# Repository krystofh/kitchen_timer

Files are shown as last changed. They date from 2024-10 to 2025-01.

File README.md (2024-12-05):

# Kitchen timer

Kitchen timer based on 4-digit 8-segment display 3461BS and RP Pico

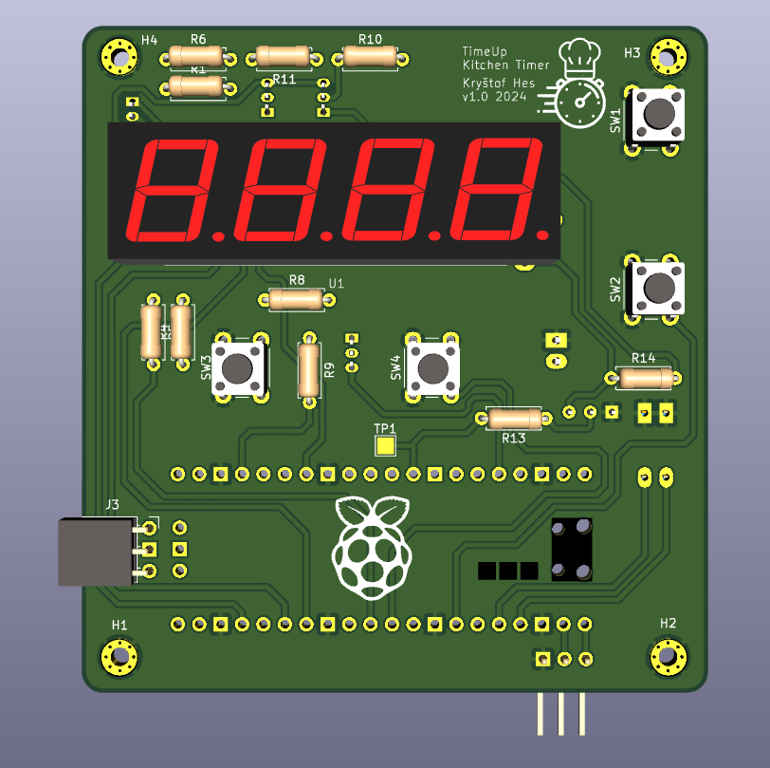
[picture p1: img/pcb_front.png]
||
|-|
|**Front view of the PCB**|

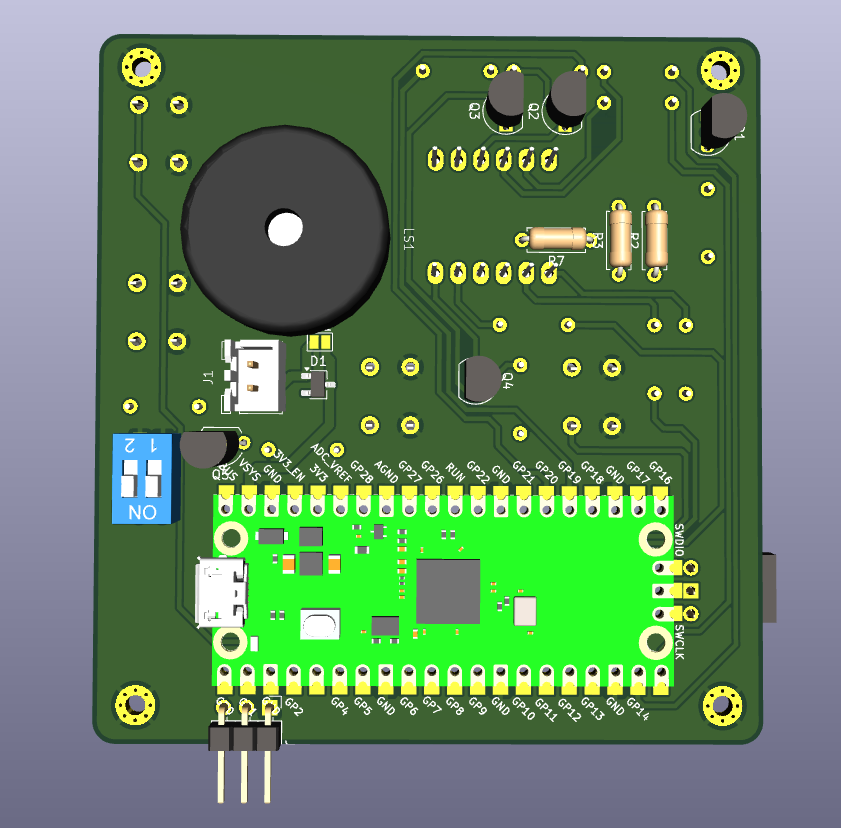
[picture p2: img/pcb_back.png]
||
|-|
|**Back view of the PCB**|

## Electronics

The used display is a common anode display. The datasheet specifies 10 mA typical current for the optical characteristics of a segment. The GPIOs of RP Pico can provide 12 mA max. The built-in `3V3OUT` voltage regulator can output up to 300 mA, which is sufficient for all 8 segemts. Not the full 32 segments are needed since the digits are displayed with a given refresh rate sequentially once at a time. Simulation using LTSpice and PNP transistor `BCS327-25` leads to the choice of resistor value

s with 220 Ohm and 22k. For the edge cases "1 segment" and "8 segments" the current limitations are fulfilled.

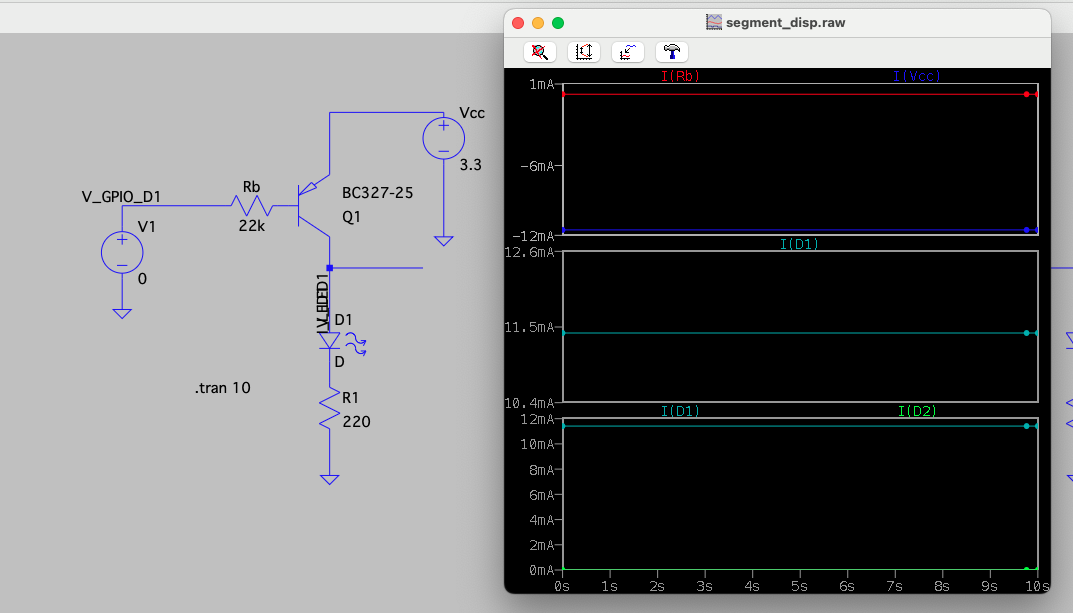
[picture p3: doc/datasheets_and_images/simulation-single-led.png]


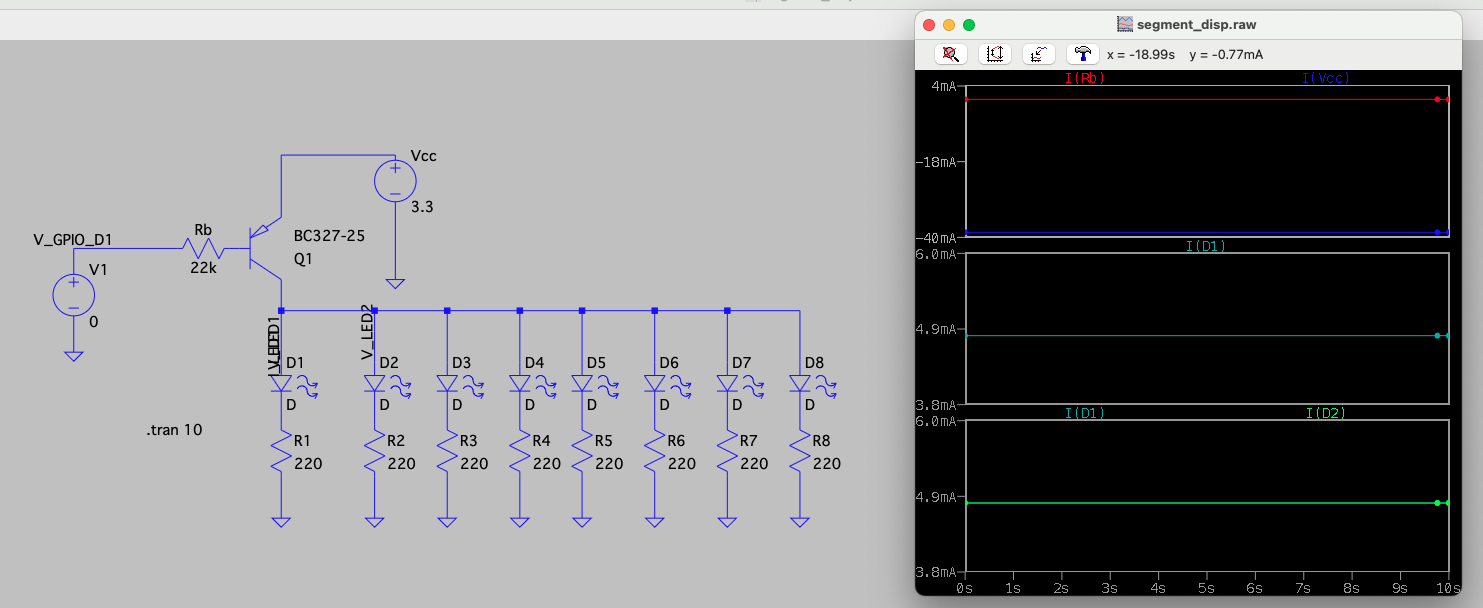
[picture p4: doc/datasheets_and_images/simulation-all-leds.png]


## Zephyr RTOS

### Setting PWM on a pin

1.  Start by enabling PWM in the `prj.conf` file: `CONFIG_PWM=y`
2.  In the `.overlay` file, enable the node `pwm_led0` by setting the status:
    ```c
    &pwm_led0 {
	status = "okay";
    };
    ```
3. Check the PWM generator corresponding to the GPIO. For RP Pico, these are:
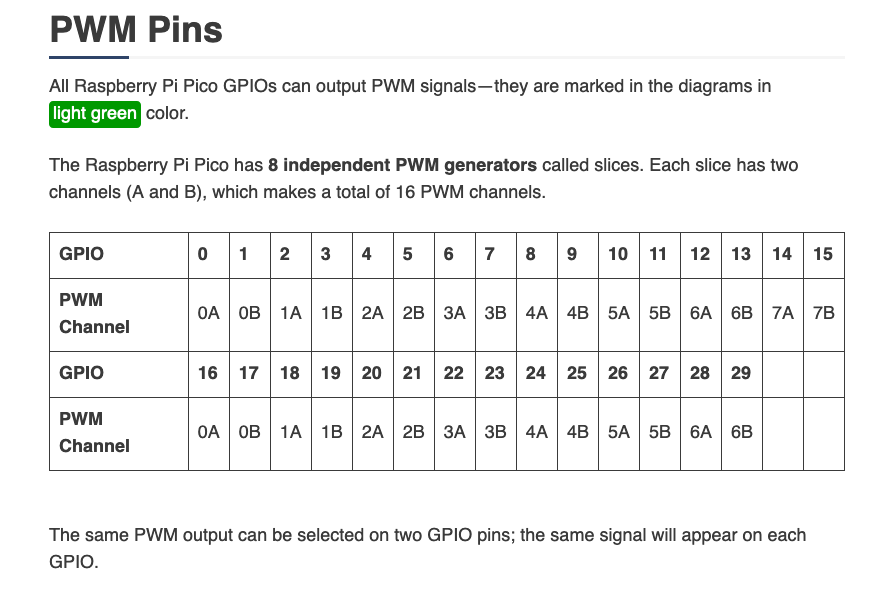
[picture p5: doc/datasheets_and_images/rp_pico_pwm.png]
PWM generators
    

    It results in a table:
    |PWM channel Nr.|PWM channel| GPIO|
    |-|-|-|
    |0|0A|0|
    |1|0B|1|
    |2|1A|2|
    |..|..|..|
    |15|7B|15|
    |0 ❗|0A|16|
    |1|0B|17|

    This means that to set PWM ON GPIO 27, we will need `PWM 5B` with the number `11`.

4. In the `.dts` file (not the overlay!), edit the `pwm_leds` node:
   ```c
    pwm_leds {
		compatible = "pwm-leds";
		status = "disabled";
		pwm_led0: pwm_led_0 {
			pwms = <&pwm 11 PWM_MSEC(20) PWM_POLARITY_NORMAL>;
			label = "PWM_LED";
		};
	};
   ```
5. Next, set the PWM on the specific pin. In the `rpi_pico-common.dtsi`:
   ```c
    &pwm {
	pinctrl-0 = <&pwm_ch5b_default>;
	pinctrl-names = "default";
    };
   ```
6. Finally, add the pinmux in `rpi_pico-pinctrl.dtsi` for GPIO 27:
   ```c
   pwm_ch5b_default: pwm_ch5b_default {
		group1 {
			pinmux = <PWM_5B_P27>;
		};
	};
   ```
7. Follow the examples such as [PWM Blinky](https://docs.zephyrproject.org/latest/samples/basic/blinky_pwm/README.html#pwm-blinky) and compile them with the changed devicetree. If it works, start coding your own application.

## Device tree definitions

Device tree nodes are aliased like in the picture below. The change from `-` to `_` is mandatory!

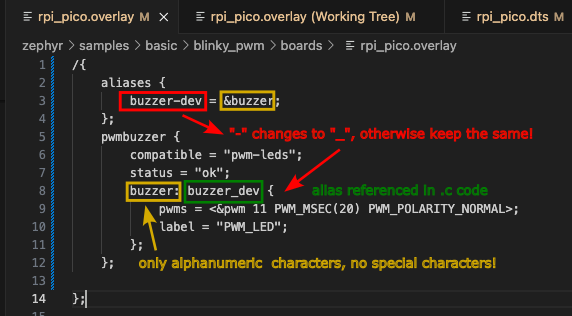
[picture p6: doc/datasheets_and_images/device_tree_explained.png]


In the `.c` code, the alias is used like:

```c
static const struct pwm_dt_spec my_variable = PWM_DT_SPEC_GET(DT_ALIAS(buzzer_dev));
```
 
## Links

- 
- https://www.electronics-tutorials.ws/blog/7-segment-display-tutorial.html
- https://www.instructables.com/12-Pin-7-Segment-Display-Wiring-Tutorial/
- https://www.reddit.com/r/AskElectronics/comments/oti47u/what_is_the_purpose_of_the_transistors_when_using/
- https://www.youtube.com/watch?v=sKJuzInKj_M
- https://www.youtube.com/watch?v=256VQ6eVNng
- https://www.youtube.com/watch?v=Fa7BHbPAM98

- Switch debouncing https://zephyrproject.org/how-to-debounce-button-inputs-in-a-rtos/
- PWM https://blog.golioth.io/adding-pwm-sound-in-zephyr/

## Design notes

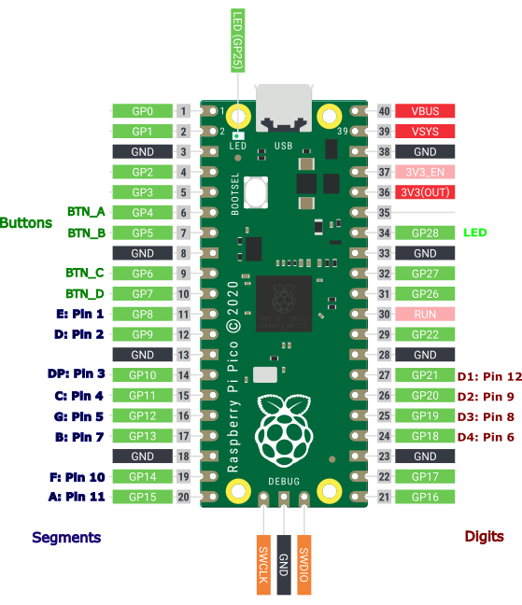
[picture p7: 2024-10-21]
electronics/datasheets_and_images/rp_pico_pinout..png

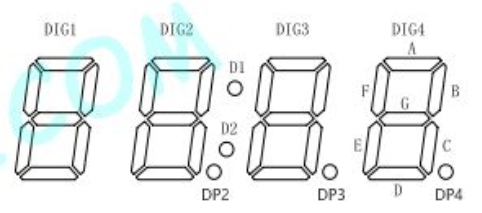
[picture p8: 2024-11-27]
electronics/kitchen_timer/display.png

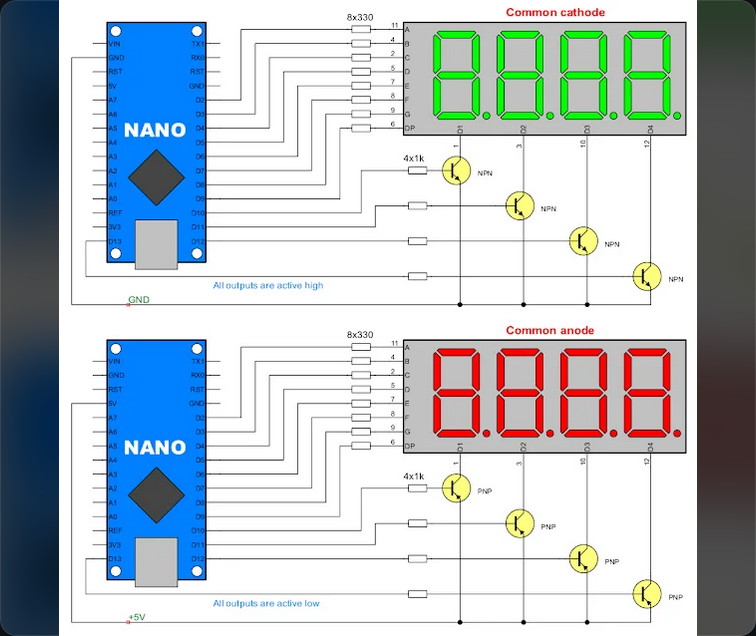
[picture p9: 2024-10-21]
electronics/datasheets_and_images/schematics-transistor.png

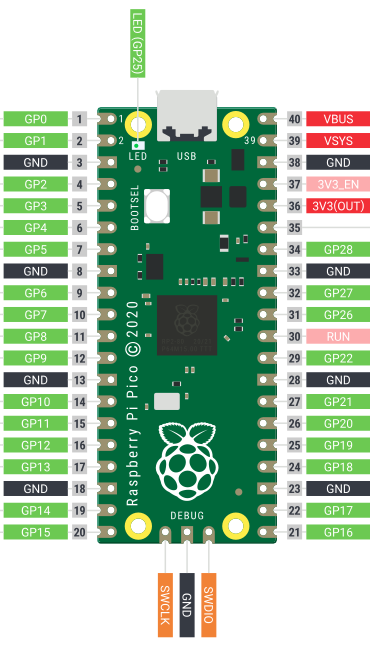
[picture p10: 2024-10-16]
electronics/datasheets_and_images/rp_pinout.png

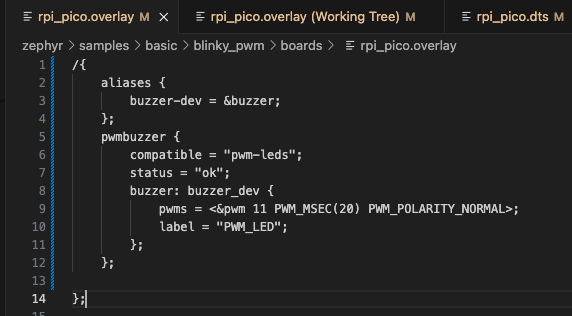
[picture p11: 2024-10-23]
img/device_tree.png

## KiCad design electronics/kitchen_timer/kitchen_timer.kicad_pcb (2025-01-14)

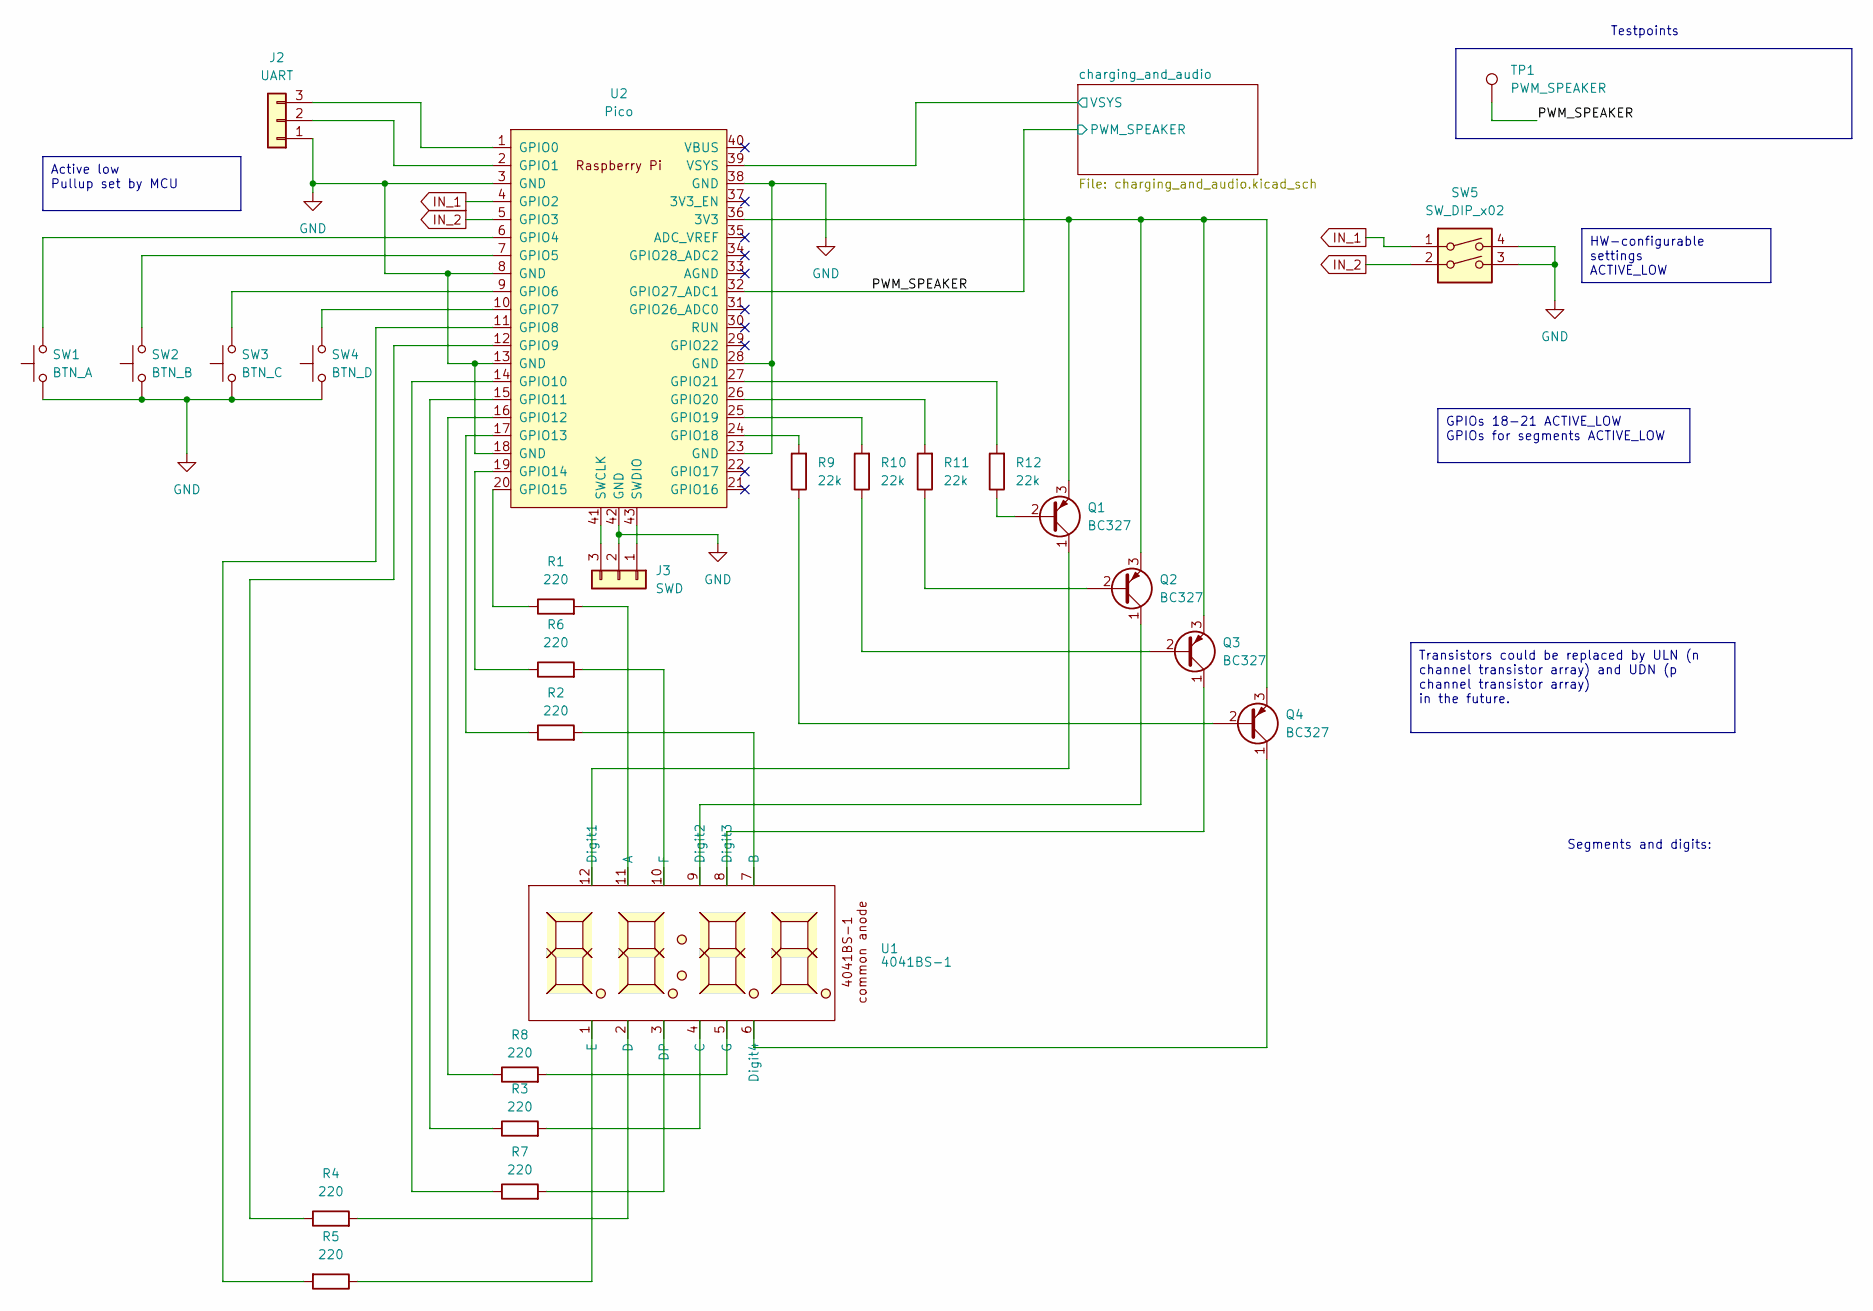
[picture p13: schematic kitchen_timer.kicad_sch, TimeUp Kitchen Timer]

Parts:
J2: UART; PinHeader_1x03_P2.54mm_Horizontal
J3: SWD; PinSocket_1x03_P2.54mm_Horizontal
Q1, Q2, Q3, Q4: BC327; TO-92_Inline
R1, R2, R3, R4, R5, R6, R7, R8: 220; R_Axial_DIN0207_L6.3mm_D2.5mm_P10.16mm_Horizontal
R9, R10, R11, R12: 22k; R_Axial_DIN0207_L6.3mm_D2.5mm_P10.16mm_Horizontal
SW1: BTN_A; SW_PUSH_6mm_H4.3mm
SW2: BTN_B; SW_PUSH_6mm_H4.3mm
SW3: BTN_C; SW_PUSH_6mm_H4.3mm
SW4: BTN_D; SW_PUSH_6mm_H4.3mm
SW5: SW_DIP_x02; DIP-4_W7.62mm_LongPads
TP1: PWM_SPEAKER; TestPoint_Pad_2.0x2.0mm
U1: 4041BS-1; Segment_display_4041BS-1
U2: Pico; RPi_Pico_SMD_TH

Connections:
/PWM_SPEAKER: TP1.1, U2.32 (GPIO27_ADC1); also elsewhere on the board
GND: J2.1, J3.2, SW1.1, SW2.1, SW3.1, SW4.1, SW5.3, SW5.4, U2.3 (GND), U2.8 (GND), U2.13 (GND), U2.18 (GND), U2.23 (GND), U2.28 (GND), U2.38 (GND), U2.42 (GND); also elsewhere on the board
IN_1: SW5.1, U2.4 (GPIO2)
IN_2: SW5.2, U2.5 (GPIO3)
unnamed: J2.2, U2.2 (GPIO1)
unnamed: J2.3, U2.1 (GPIO0)
unnamed: J3.1, U2.43 (SWDIO)
unnamed: J3.3, U2.41 (SWCLK)
unnamed: Q1.2 (B), R12.1
unnamed: Q1.1 (C), U1.12 (Digit1)
unnamed: Q1.3 (E), Q2.3 (E), Q3.3 (E), Q4.3 (E), U2.36 (3V3)
unnamed: Q2.2 (B), R11.1
unnamed: Q2.1 (C), U1.9 (Digit2)
unnamed: Q3.2 (B), R10.1
unnamed: Q3.1 (C), U1.8 (Digit3)
unnamed: Q4.2 (B), R9.1
unnamed: Q4.1 (C), U1.6 (Digit4)
unnamed: R1.2, U1.11 (A)
unnamed: R2.2, U1.7 (B)
unnamed: R3.2, U1.4 (C)
unnamed: R4.2, U1.2 (D)
unnamed: R7.2, U1.3 (DP)
unnamed: R5.1, U1.1 (E)
unnamed: R6.2, U1.10 (F)
unnamed: R8.2, U1.5 (G)
unnamed: SW1.2, U2.6 (GPIO4)
unnamed: SW2.2, U2.7 (GPIO5)
unnamed: SW3.2, U2.9 (GPIO6)
unnamed: SW4.2, U2.10 (GPIO7)
unnamed: R5.2, U2.11 (GPIO8)
unnamed: R4.1, U2.12 (GPIO9)
unnamed: R7.1, U2.14 (GPIO10)
unnamed: R3.1, U2.15 (GPIO11)
unnamed: R8.1, U2.16 (GPIO12)
unnamed: R2.1, U2.17 (GPIO13)
unnamed: R6.1, U2.19 (GPIO14)
unnamed: R1.1, U2.20 (GPIO15)
unnamed: R9.2, U2.24 (GPIO18)
unnamed: R10.2, U2.25 (GPIO19)
unnamed: R11.2, U2.26 (GPIO20)
unnamed: R12.2, U2.27 (GPIO21)

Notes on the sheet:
Active low Pullup set by MCU
Transistors could be replaced by ULN (n channel transistor array) and UDN (p channel transistor array) in the future.
HW-configurable settings ACTIVE_LOW
GPIOs 18-21 ACTIVE_LOW GPIOs for segments ACTIVE_LOW
Segments and digits:
Testpoints

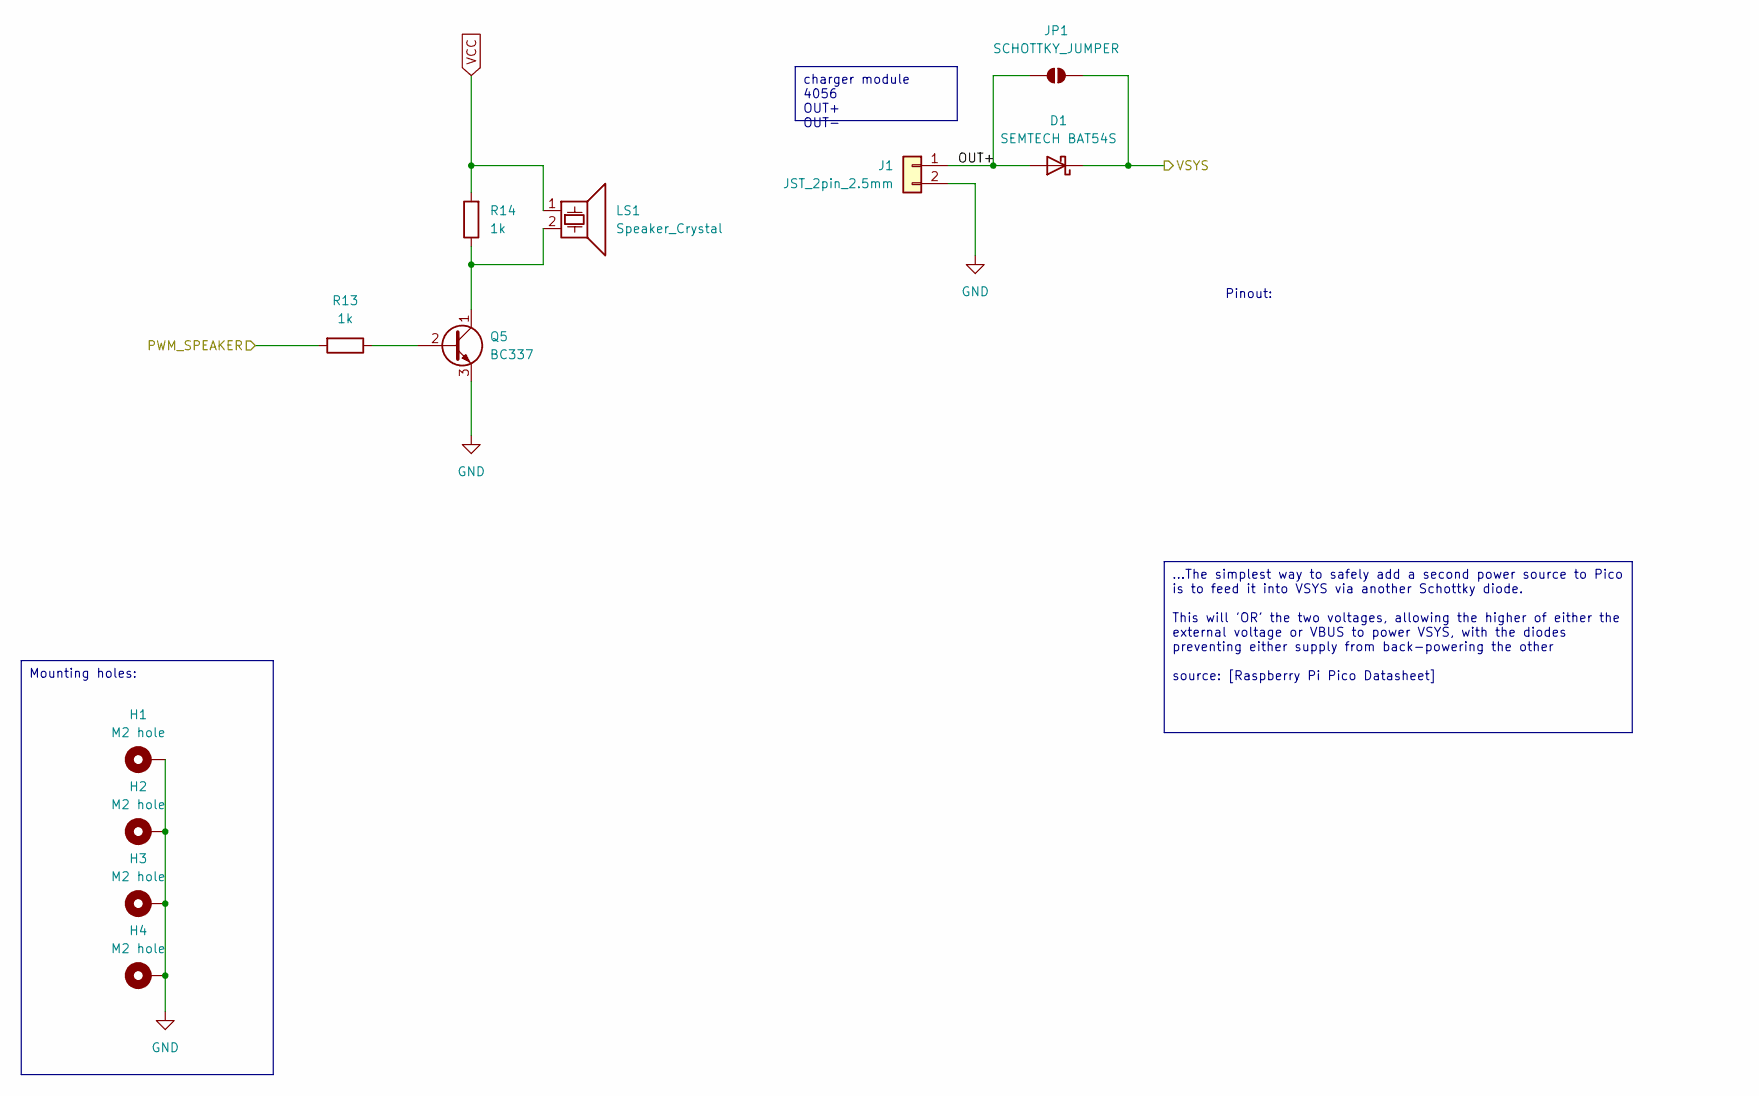
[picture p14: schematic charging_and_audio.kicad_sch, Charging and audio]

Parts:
D1: SEMTECH BAT54S; SOT-23_Handsoldering_renumbered
H1, H2, H3, H4: M2 hole; MountingHole_2.2mm_M2_Pad_Via
J1: JST_2pin_2.5mm; JST_2pin_2.54mm_female
JP1: SCHOTTKY_JUMPER; SolderJumper-2_P1.3mm_Open_TrianglePad1.0x1.5mm
LS1: Speaker_Crystal; Piezzo_10mm_6.5mm_combined
Q5: BC337; TO-92L_Inline_Wide
R13, R14: 1k; R_Axial_DIN0207_L6.3mm_D2.5mm_P10.16mm_Horizontal

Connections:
/PWM_SPEAKER: R13.2; also elsewhere on the board
GND: H1.1, H2.1, H3.1, H4.1, J1.2, Q5.3 (E); also elsewhere on the board
unnamed: Q5.2 (B), R13.1
unnamed: LS1.2, Q5.1 (C), R14.1
VCC: LS1.1, R14.2

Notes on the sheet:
...The simplest way to safely add a second power source to Pico is to feed it into VSYS via another Schottky diode. This will 'OR' the two voltages, allowing the higher of either the external voltage or VBUS to power VSYS, with the diodes preventing either supply from back-powering the other source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
Mounting holes:
charger module 4056 OUT+ OUT-
Pinout:

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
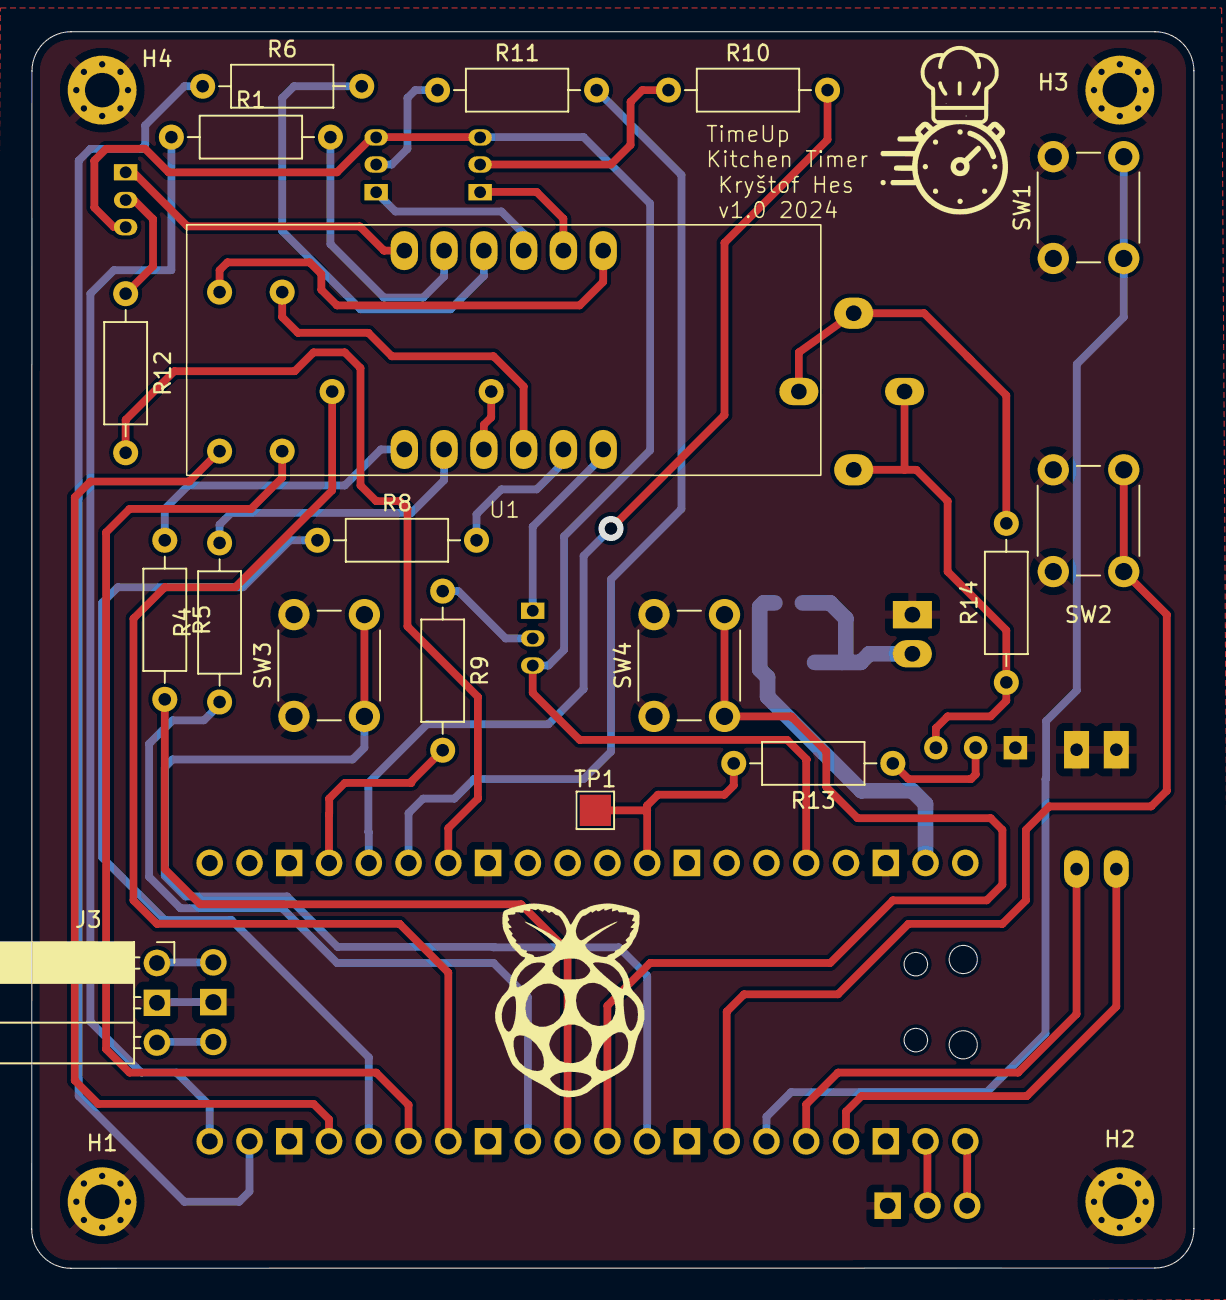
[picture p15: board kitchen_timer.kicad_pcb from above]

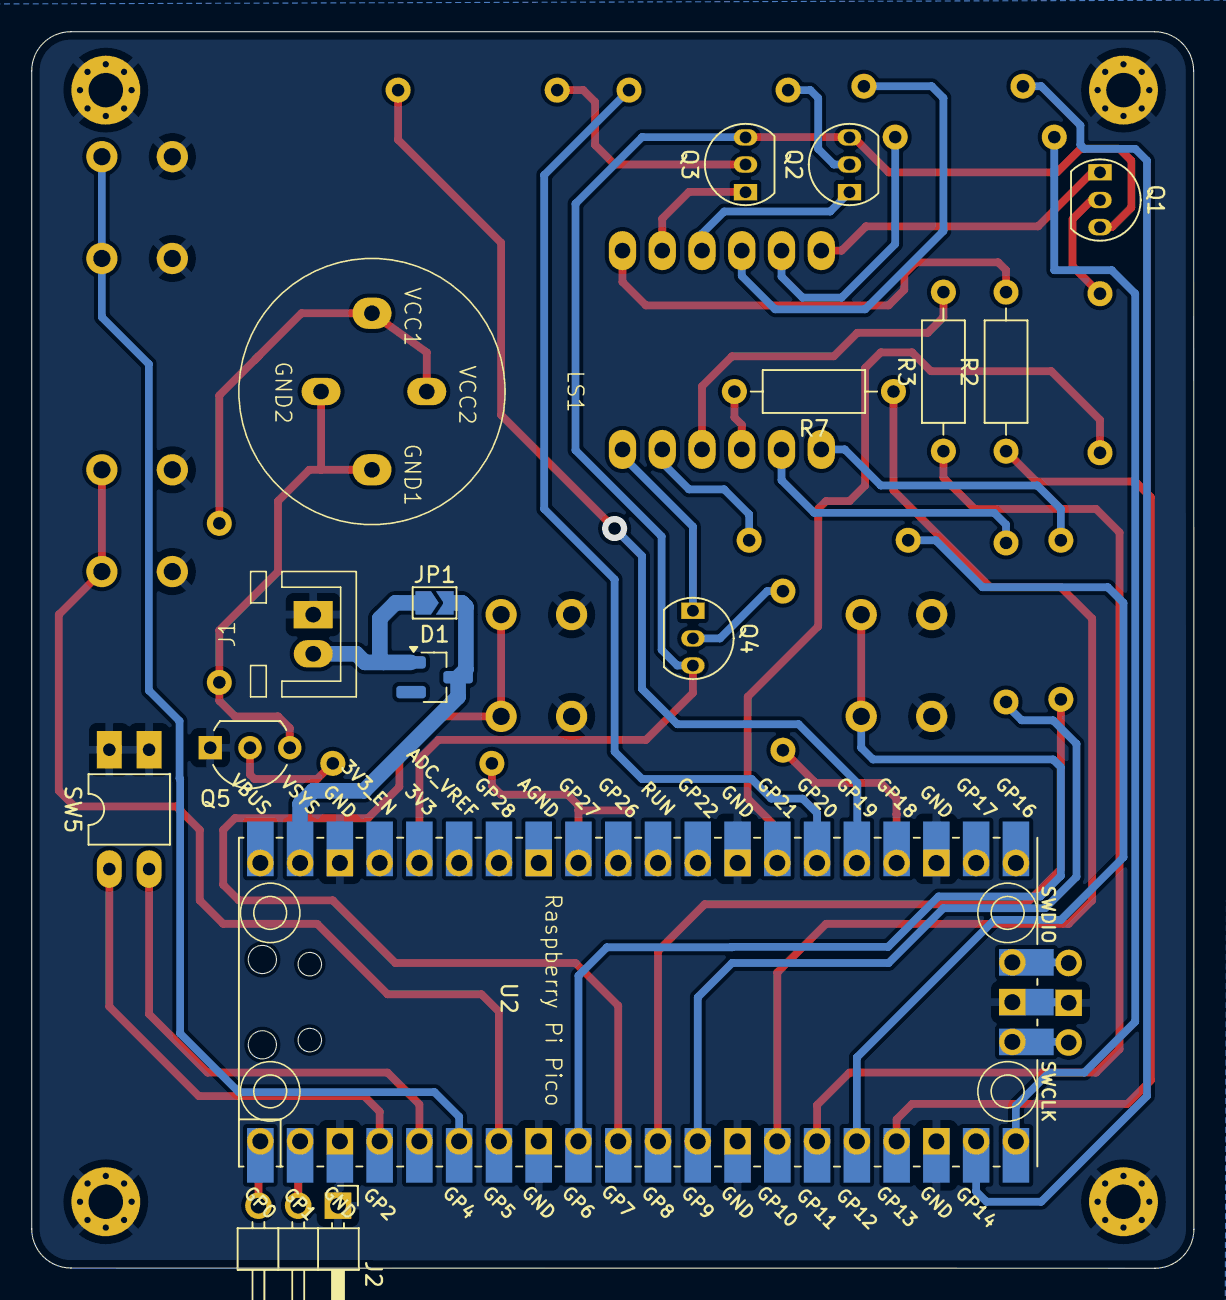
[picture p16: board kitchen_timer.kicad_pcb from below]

Board: 2 copper layers, 74.2 x 79.0 mm, 37 parts (15 on the bottom side), 46 nets.

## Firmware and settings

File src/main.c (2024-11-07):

/*
 * Copyright (c) 2016 Intel Corporation
 *
 * SPDX-License-Identifier: Apache-2.0
 */

#include <stdio.h>
#include <string.h>
#include <stdlib.h>
#include <ctype.h>

// Zephyr-specific libs
#include <zephyr/kernel.h>
#include <zephyr/drivers/gpio.h>
#include <zephyr/logging/log.h>
#include <zephyr/sys/printk.h>
#include <zephyr/sys/util.h>
#include <zephyr/usb/usb_device.h>
#include <zephyr/drivers/uart.h>
#include <zephyr/drivers/pwm.h>
// Shell libs
#include <zephyr/kernel.h>
#include <zephyr/shell/shell.h>
#include <zephyr/version.h>

// Own code
#include "display_driver.h"
#include "timer.h"
#include "event_handler.h"
#include "sound_player.h"

/* 1000 msec = 1 sec */
#define SLEEP_TIME_MS 20
// Define the alias for the onboard LED
#define STATUS_LED_NODE DT_NODELABEL(status_led)
/*
 * Ensure that an overlay for USB serial has been defined.
 */
BUILD_ASSERT(DT_NODE_HAS_COMPAT(DT_CHOSEN(zephyr_console), zephyr_cdc_acm_uart),
			 "Console device is not ACM CDC UART device");

LOG_MODULE_REGISTER(main, CONFIG_MAIN_LOG_LEVEL); // registers the log level for the module MAIN specified in Kconfig

const struct gpio_dt_spec status_led = GPIO_DT_SPEC_GET(STATUS_LED_NODE, gpios); // onboard LED device
const struct pwm_dt_spec buzzer = PWM_DT_SPEC_GET(DT_ALIAS(buzzer_dev));		 // buzzer for sound

// initialise all LED devices
int init_leds()
{
	int ret;
	if (!gpio_is_ready_dt(&status_led))
	{
		return 1;
	}
	ret = gpio_pin_configure_dt(&status_led, GPIO_OUTPUT_ACTIVE);
	if (ret < 0)
	{
		return 1;
	}
	return 0;
}

int main(void)
{
	LOG_INF("Program starting\n"); // example info message

	// Init sound
	init_sound(&buzzer);

	// Init the LED devices in logic 1 state
	if (init_leds())
	{
		LOG_ERR("LEDs could not be initialised!");
	}
	else
	{
		LOG_INF("LED devices initialised properly");
	}

	// Shell config
	const struct device *dev;
	uint32_t dtr = 0;
	dev = DEVICE_DT_GET(DT_CHOSEN(zephyr_shell_uart));
	if (!device_is_ready(dev) || usb_enable(NULL))
	{
		return 0;
	}
	uart_line_ctrl_get(dev, UART_LINE_CTRL_DTR, &dtr);
	k_sleep(K_MSEC(100));
	LOG_INF("USB device configured and connected");

	// Button config
	if (init_buttons())
	{
		LOG_ERR("Button init failed!");
	}
	else
	{
		LOG_INF("Button init successful!");
	}

	// Display init
	if (init_display())
	{
		LOG_ERR("Display init failed!");
	}
	else
	{
		LOG_INF("Display init successful!");
	}

	// Wait in this loop for shell commands or process messages
	while (true)
	{
		/* If we have an LED, match its state to the button's. */
		k_msleep(SLEEP_TIME_MS); /* sleep x ms*/
	}
	return 0;
}

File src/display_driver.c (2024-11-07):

#include "display_driver.h"

#define STACK_SIZE 1024
#define DISP_THREAD_PRIORITY 5

LOG_MODULE_REGISTER(display, CONFIG_DISPLAY_LOG_LEVEL);

// Digits GPIO configuration (active high)
const struct gpio_dt_spec digit_1 = GPIO_DT_SPEC_GET(DT_NODELABEL(d1), gpios);
const struct gpio_dt_spec digit_2 = GPIO_DT_SPEC_GET(DT_NODELABEL(d2), gpios);
const struct gpio_dt_spec digit_3 = GPIO_DT_SPEC_GET(DT_NODELABEL(d3), gpios);
const struct gpio_dt_spec digit_4 = GPIO_DT_SPEC_GET(DT_NODELABEL(d4), gpios);

// Segment GPIO configuration (active low)
const struct gpio_dt_spec seg_a = GPIO_DT_SPEC_GET(DT_NODELABEL(sega), gpios);
const struct gpio_dt_spec seg_b = GPIO_DT_SPEC_GET(DT_NODELABEL(segb), gpios);
const struct gpio_dt_spec seg_c = GPIO_DT_SPEC_GET(DT_NODELABEL(segc), gpios);
const struct gpio_dt_spec seg_d = GPIO_DT_SPEC_GET(DT_NODELABEL(segd), gpios);
const struct gpio_dt_spec seg_e = GPIO_DT_SPEC_GET(DT_NODELABEL(sege), gpios);
const struct gpio_dt_spec seg_f = GPIO_DT_SPEC_GET(DT_NODELABEL(segf), gpios);
const struct gpio_dt_spec seg_g = GPIO_DT_SPEC_GET(DT_NODELABEL(segg), gpios);
const struct gpio_dt_spec seg_dp = GPIO_DT_SPEC_GET(DT_NODELABEL(segdp), gpios);

// Digits and segments
const struct gpio_dt_spec *digits[] = {&digit_1, &digit_2, &digit_3, &digit_4};
const struct gpio_dt_spec *segments[] = {&seg_a, &seg_b, &seg_c, &seg_d, &seg_e, &seg_f, &seg_g, &seg_dp};
// Buffer to store the current digits to display
uint8_t display_buffer[4] = {0, 0, 0, 0};

// Digit encoding
// 7-segment encoding for digits 0-9
const uint8_t digit_codes[10] = {
    0b00111111, // 0
    0b00000110, // 1
    0b01011011, // 2
    0b01001111, // 3
    0b01100110, // 4
    0b01101101, // 5
    0b01111101, // 6
    0b00000111, // 7
    0b01111111, // 8
    0b01101111  // 9
};

// Spawn thread
K_THREAD_DEFINE(display_refresh_tid, STACK_SIZE, display_refresh_thread, NULL, NULL, NULL,
                DISP_THREAD_PRIORITY, 0, 0);

// Initialize the display GPIOs
int init_display()
{
    int ret;

    // Configure digit GPIOs
    ret = gpio_pin_configure_dt(&digit_1, GPIO_OUTPUT_INACTIVE);
    if (ret != 0)
        return ret;

    ret = gpio_pin_configure_dt(&digit_2, GPIO_OUTPUT_INACTIVE);
    if (ret != 0)
        return ret;

    ret = gpio_pin_configure_dt(&digit_3, GPIO_OUTPUT_INACTIVE);
    if (ret != 0)
        return ret;

    ret = gpio_pin_configure_dt(&digit_4, GPIO_OUTPUT_INACTIVE);
    if (ret != 0)
        return ret;

    // Configure segment GPIOs
    ret = gpio_pin_configure_dt(&seg_a, GPIO_OUTPUT_INACTIVE);
    if (ret != 0)
        return ret;

    ret = gpio_pin_configure_dt(&seg_b, GPIO_OUTPUT_INACTIVE);
    if (ret != 0)
        return ret;

    ret = gpio_pin_configure_dt(&seg_c, GPIO_OUTPUT_INACTIVE);
    if (ret != 0)
        return ret;

    ret = gpio_pin_configure_dt(&seg_d, GPIO_OUTPUT_INACTIVE);
    if (ret != 0)
        return ret;

    ret = gpio_pin_configure_dt(&seg_e, GPIO_OUTPUT_INACTIVE);
    if (ret != 0)
        return ret;

    ret = gpio_pin_configure_dt(&seg_f, GPIO_OUTPUT_INACTIVE);
    if (ret != 0)
        return ret;

    ret = gpio_pin_configure_dt(&seg_g, GPIO_OUTPUT_INACTIVE);
    if (ret != 0)
        return ret;

    ret = gpio_pin_configure_dt(&seg_dp, GPIO_OUTPUT_INACTIVE);
    if (ret != 0)
        return ret;

    LOG_INF("Display initialized");
    return 0;
}

void display_refresh_thread()
{
    while (1)
    {
        for (uint8_t i = 0; i < ARRAY_SIZE(digits); i++)
        {
            display_digit(display_buffer[i], i);
            k_sleep(K_MSEC(1000 / (ARRAY_SIZE(digits) * CONFIG_DISPLAY_FPS))); // period [ms]
        }
    }
}

// Simple demo showing sequentially all segments on all digits
int display_demo()
{
    bool enable_shutdown = false;
    // Iterate through each digit in digits
    for (int i = 0; i < ARRAY_SIZE(digits); i++)
    {
        // Turn off all segemnts first
        for (int m = 0; m < ARRAY_SIZE(segments); m++)
        {
            gpio_pin_set_dt(segments[m], 0);
        }

        // Turn off all digits first to prevent ghosting
        for (int j = 0; j < ARRAY_SIZE(digits); j++)
        {
            gpio_pin_set_dt(digits[j], 0);
        }

        // Activate current digit
        int response = gpio_pin_set_dt(digits[i], 1);

        // Light up each segment (A to G, DP) sequentially
        response = gpio_pin_set_dt(&seg_a, 1); // try out segment A
        k_sleep(K_MSEC(1000));
        if (enable_shutdown)
        {
            gpio_pin_set_dt(&seg_a, 0);
        };
        response = gpio_pin_set_dt(&seg_b, 1); // try out segment
        k_sleep(K_MSEC(1000));
        if (enable_shutdown)
        {
            response = gpio_pin_set_dt(&seg_b, 0); // try out segment
        };
        response = gpio_pin_set_dt(&seg_c, 1); // try out segment
        k_sleep(K_MSEC(1000));
        if (enable_shutdown)
        {
            response = gpio_pin_set_dt(&seg_c, 0); // try out segment
        };
        response = gpio_pin_set_dt(&seg_d, 1); // try out segment
        k_sleep(K_MSEC(1000));
        if (enable_shutdown)
        {
            response = gpio_pin_set_dt(&seg_d, 0); // try out segment
        };
        response = gpio_pin_set_dt(&seg_e, 1); // try out segment
        k_sleep(K_MSEC(1000));
        if (enable_shutdown)
        {
            response = gpio_pin_set_dt(&seg_e, 0); // try out segment
        }
        response = gpio_pin_set_dt(&seg_f, 1); // try out segment
        k_sleep(K_MSEC(1000));
        if (enable_shutdown)
        {
            response = gpio_pin_set_dt(&seg_f, 0); // try out segment
        }
        response = gpio_pin_set_dt(&seg_g, 1); // try out segment
        k_sleep(K_MSEC(1000));
        if (enable_shutdown)
        {
            response = gpio_pin_set_dt(&seg_g, 0); // try out segment
        }
        response = gpio_pin_set_dt(&seg_dp, 1); // try out segment
        k_sleep(K_MSEC(1000));
        if (enable_shutdown)
        {
            response = gpio_pin_set_dt(&seg_dp, 0); // try out segment
        };
    }
    return 0;
}

// Display a diven digit
// index - 0 to 3,  HH:MM
void display_digit(uint8_t digit, uint8_t index)
{
    reset_display(); // make sure only one digit is displayed at a time
    // prepare the digit's index (select the 8-bit segment)
    gpio_pin_set_dt(digits[index], 1);
    // draw the digit
    uint8_t temp_bin = digit_codes[digit];             // binary representation of digit
    for (uint8_t i = 0; i < ARRAY_SIZE(segments); i++) // go through one segment (bit) after the other
    {
        gpio_pin_set_dt(segments[i], temp_bin % 2); // if the bit is 1 -> set the segment ACTIVE
        temp_bin = temp_bin >> 1;                   // right shift after the bit is processed
    }
}
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

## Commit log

2024-10-16 empty west repo for rp pico
2024-10-16 prepared device tree
2024-10-16 minimal working example of button A
2024-10-21 added buttons C and D for future minute and second selection
2024-10-23 button debounce partly working
2024-10-23 device tree and electronics explanations
2024-11-07 corrected time pointers, added reset cmd
    [event_handler.c, main.c]
2024-11-07 timer min example
2024-11-07 refactor timer as separate file from event handler
2024-11-07 added start stop reset sounds
    [sound_player.c]
2024-11-08 alarm loop until button pressed
2024-11-16 change VID and PID and product
2024-11-20 Add debounce for all buttons
2024-11-20 Change button C function
    C can start and stop timer
    C can reset timer on longpress
    [event_handler.c]
2024-11-27 add electronics files
    [charging_and_audio.kicad_sch, kitchen_timer.kicad_pcb, kitchen_timer.kicad_sch]
2024-11-27 Add 3d models to components, small rerouting
    [charging_and_audio.kicad_sch, kitchen_timer.kicad_pcb, kitchen_timer.kicad_sch]
2024-12-05 Update electronics
    - added Schottky diode and solder bridge
    - corrected all errors from design rules checker
    - added silk screen logos
    [charging_and_audio.kicad_sch, kitchen_timer.kicad_pcb, kitchen_timer.kicad_sch]
2024-12-07 Update electronics
    - resistors with longer spacing between holes
    - GND for SWD
    - solder jumper new footprint
    - increase distances between nets
    - added datasheet for schottky
    [charging_and_audio.kicad_sch, kitchen_timer.kicad_pcb, kitchen_timer.kicad_sch]
2025-01-14 add:gerber files export to JLCPCB
    [kitchen_timer-B_Cu.gbl, kitchen_timer-B_Mask.gbs, kitchen_timer-B_Paste.gbp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]
2025-01-30 chore: add notes on needed fixes
    [kitchen_timer.kicad_sch]
